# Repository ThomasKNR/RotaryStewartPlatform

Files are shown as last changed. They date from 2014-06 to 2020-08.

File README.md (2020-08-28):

Rotary Stewart Platform
-----------------------

In this repository are source files for a Rotary Stewart Platform project. This project is for a small Stewart platform controlled by RC servos and Arduino. Stewart Platform is a parallel robot capable of positioning its moving platform in 6 degrees of freedom. In this project, platform has additional features such as an LCD to show various data and IrDA used for remote controlling of its movements. Main informations about this project and detailed description of a construction process can be found at http://www.instructables.com/id/Arduino-controlled-Rotary-Stewart-Platform/.

Source files are divided into three main folders:

- **src_arduino_code** - contains souce code files and needed libraries for Arduino:
 - for controlling LCD via I2C interface: https://bitbucket.org/fmalpartida/new-liquidcrystal/wiki/Home
 -  for IrDA communication: https://github.com/shirriff/Arduino-IRremote/wiki
- **src_comm_lib** - contains communication library for controlling this platform, it is written in C++ and uses serial communication to communicate with arduino. This library works on Windows and on Linux, it is used for easy control of platform movements.
- **templates_for_cutting** - DXF files containing templates for laser cutting of parts from plastic and also PCB layout for board needed for external supply of power to servos. These files were made using QCad tool.

In IrDA communication library there are made tiny changes - because servo and also IrDA library need interrupt handling, there were problems when using servos and IrDA communication at the same time, these changes reduce consequence of these problems, consequences were very subtle random servo movements.

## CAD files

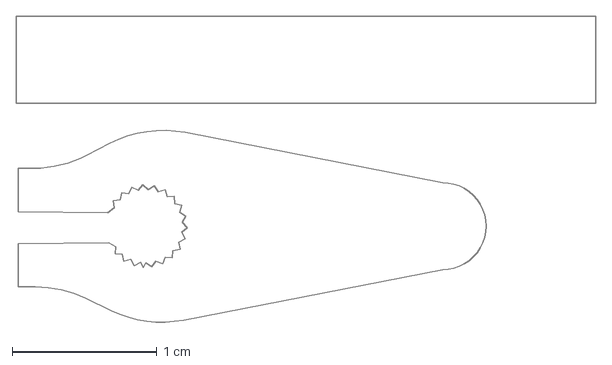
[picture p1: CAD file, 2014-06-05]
templates_for_cutting/servo_arm.dxf
4.00 x 2.13 cm

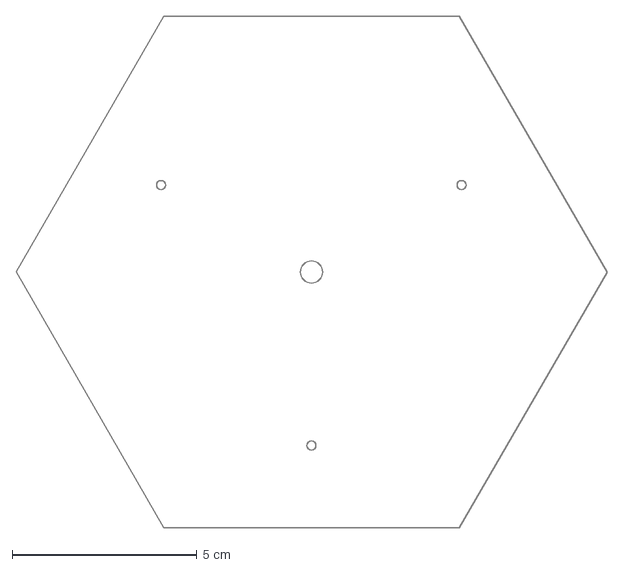
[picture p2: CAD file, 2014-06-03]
templates_for_cutting/platform_top.dxf
16.0 x 13.9 cm

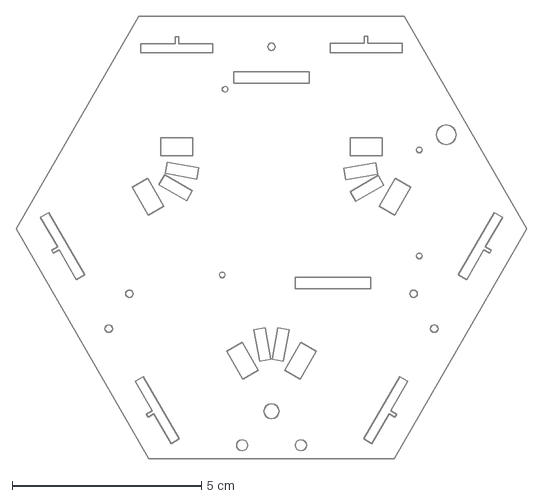
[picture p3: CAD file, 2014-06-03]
templates_for_cutting/base_top.dxf
13.5 x 11.7 cm

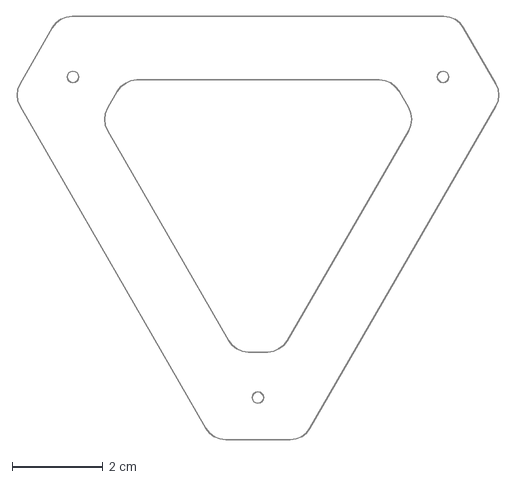
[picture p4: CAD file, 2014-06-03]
templates_for_cutting/platform_bot.dxf
10.6 x 9.31 cm

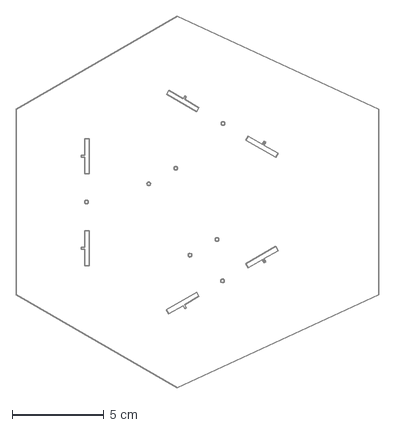
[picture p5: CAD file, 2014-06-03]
templates_for_cutting/base_bot.dxf
19.8 x 20.3 cm

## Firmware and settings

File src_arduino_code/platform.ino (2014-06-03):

/* <Controlling code for Arduino Controlled Rotary Stewart Platform>
    Copyright (C) <2014>  <Tomas Korgo>

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
    You should have received a copy of the GNU General Public License
    along with this program.  If not, see <http://www.gnu.org/licenses/>.*/

#include <Servo.h>
#include <Wire.h>
#include <LCD.h>
#include <LiquidCrystal_I2C.h>
#include <IRremote.h>

//define values of IrDA codes send from used remote control
#define MUTE_BUTTON 0x807F906F
#define STANDBY_ON 0x807F20DF
#define VOL_UP 0x807F609F
#define VOL_DOWN 0x807FA05F
#define DVD 0x807F08F7
#define TV 0x807F8877
#define GAME 0x807F48B7
#define CD 0x807FC837

//define of characters used for control of serial communication ['0'-'8']
#define SETBACKOFF 48
#define SETBACKON 49
#define SETPOSITIONS 50
#define PRINTPOS 51
#define STOPPRINTPOS 52
#define SWITCHIRDA 53
#define SETPOSITIONSINMS 54
#define SWITCHIRDAOFF 55
#define GEPOSITION 56
//defines of LCD pin numbers, most probably they dont have to be changed except of I2C_ADDR which value is neccessary and have to be changed.
#define I2C_ADDR 0x27
#define LCD 1
#define IrDA 1
#define BACKLIGHT_PIN 3
#define En 2
#define Rw 1
#define Rs 0
#define D4 4
#define D5 5
#define D6 6
#define D7 7
//MIN and MAX PWM pulse sizes, they can be found in servo documentation
#define MAX 2200
#define MIN 800

//Positions of servos mounted in opposite direction
#define INV1 1
#define INV2 3
#define INV3 5

//constants for computation of positions of connection points
#define pi  3.14159
#define deg2rad 180/pi
#define deg30 pi/6
//variables used for proper show of positions on LCD
char shown=0, showPos=0, useIrda=0;
unsigned long time;

//variable to store connected LCD
LiquidCrystal_I2C lcd(I2C_ADDR, En, Rw, Rs, D4,D5,D6,D7);
//IrReciever variables
IRrecv irrecv(12); // Receive Ir on digital pin n 12
decode_results results;

//Array of servo objects
Servo servo[6];
//Zero positions of servos, in this positions their arms are perfectly horizontal, in us
static int zero[6]={1475,1470,1490,1480,1460,1490};
//In this array is stored requested position for platform - x,y,z,rot(x),rot(y),rot(z)
static float arr[6]={0,0.0,0, radians(0),radians(0),radians(0)};
//Actual degree of rotation of all servo arms, they start at 0 - horizontal, used to reduce
//complexity of calculating new degree of rotation
static float theta_a[6]={0.0,0.0,0.0, 0.0,0.0,0.0};
//Array of current servo positions in us
static int servo_pos[6];
//rotation of servo arms in respect to axis x
const float beta[] = {pi/2,-pi/2,-pi/6, 5*pi/6,-5*pi/6,pi/6},
//maximum servo positions, 0 is horizontal position
      servo_min=radians(-80),servo_max=radians(80),
//servo_mult - multiplier used for conversion radians->servo pulse in us
//L1-effective length of servo arm, L2 - length of base and platform connecting arm
//z_home - height of platform above base, 0 is height of servo arms
servo_mult=400/(pi/4),L1 = 0.79,L2 = 4.66, z_home = 4.05;
//RD distance from center of platform to attachment points (arm attachment point)
//RD distance from center of base to center of servo rotation points (servo axis)
//theta_p-angle between two servo axis points, theta_r - between platform attachment points
//theta_angle-helper variable
//p[][]=x y values for servo rotation points
//re[]{}=x y z values of platform attachment points positions
//equations used for p and re will affect postion of X axis, they can be changed to achieve
//specific X axis position
const float RD = 2.42,PD =2.99,theta_p = radians(37.5),
theta_angle=(pi/3-theta_p)/2, theta_r = radians(8),
      p[2][6]={
          {
            -PD*cos(deg30-theta_angle),-PD*cos(deg30-theta_angle),
            PD*sin(theta_angle),PD*cos(deg30+theta_angle),
            PD*cos(deg30+theta_angle),PD*sin(theta_angle)
         },
         {
            -PD*sin(deg30-theta_angle),PD*sin(deg30-theta_angle),
            PD*cos(theta_angle),PD*sin(deg30+theta_angle),
            -PD*sin(deg30+theta_angle),-PD*cos(theta_angle)
         }
      },
      re[3][6] = {
          {
              -RD*sin(deg30+theta_r/2),-RD*sin(deg30+theta_r/2),
              -RD*sin(deg30-theta_r/2),RD*cos(theta_r/2),
              RD*cos(theta_r/2),-RD*sin(deg30-theta_r/2),
          },{
              -RD*cos(deg30+theta_r/2),RD*cos(deg30+theta_r/2),
              RD*cos(deg30-theta_r/2),RD*sin(theta_r/2),
              -RD*sin(theta_r/2),-RD*cos(deg30-theta_r/2),
          },{
              0,0,0,0,0,0
          }
};
//arrays used for servo rotation calculation
//H[]-center position of platform can be moved with respect to base, this is
//translation vector representing this move
static float M[3][3], rxp[3][6], T[3], H[3] = {0,0,z_home};

void setup(){
//LCD inicialisation and turning on the backlight
#if LCD
   lcd.begin(16,2);
   lcd.setBacklightPin(BACKLIGHT_PIN, POSITIVE);
   lcd.setBacklight(HIGH);
   lcd.home();
#endif

//attachment of servos to PWM digital pins of arduino
   servo[0].attach(3, MIN, MAX);
   servo[1].attach(5, MIN, MAX);
   servo[2].attach(6, MIN, MAX);
   servo[3].attach(9, MIN, MAX);
   servo[4].attach(10, MIN, MAX);
   servo[5].attach(11, MIN, MAX);
//begin of serial communication
   Serial.begin(9600);
//putting into base position
   setPos(arr);
}

//function calculating needed servo rotation value
float getAlpha(int *i){
   static int n;
   static float th=0;
   static float q[3], dl[3], dl2;
   double min=servo_min;
   double max=servo_max;
   n=0;
   th=theta_a[*i];
   while(n<20){
    //calculation of position of base attachment point (point on servo arm where is leg connected)
      q[0] = L1*cos(th)*cos(beta[*i]) + p[0][*i];
      q[1] = L1*cos(th)*sin(beta[*i]) + p[1][*i];
      q[2] = L1*sin(th);
    //calculation of distance between according platform attachment point and base attachment point
      dl[0] = rxp[0][*i] - q[0];
      dl[1] = rxp[1][*i] - q[1];
      dl[2] = rxp[2][*i] - q[2];
      dl2 = sqrt(dl[0]*dl[0] + dl[1]*dl[1] + dl[2]*dl[2]);
    //if this distance is the same as leg length, value of theta_a is corrent, we return it
      if(abs(L2-dl2)<0.01){
         return th;
      }
    //if not, we split the searched space in half, then try next value
      if(dl2<L2){
         max=th;
      }else{
         min=th;
      }
      n+=1;
      if(max==servo_min || min==servo_max){
         return th;
      }
      th = min+(max-min)/2;
   }
   return th;
}

//function calculating rotation matrix
void getmatrix(float pe[])
{
   float psi=pe[5];
   float theta=pe[4];
   float phi=pe[3];
   M[0][0] = cos(psi)*cos(theta);
   M[1][0] = -sin(psi)*cos(phi)+cos(psi)*sin(theta)*sin(phi);
   M[2][0] = sin(psi)*sin(phi)+cos(psi)*cos(phi)*sin(theta);

   M[0][1] = sin(psi)*cos(theta);
   M[1][1] = cos(psi)*cos(phi)+sin(psi)*sin(theta)*sin(phi);
   M[2][1] = cos(theta)*sin(phi);

   M[0][2] = -sin(theta);
   M[1][2] = -cos(psi)*sin(phi)+sin(psi)*sin(theta)*cos(phi);
   M[2][2] = cos(theta)*cos(phi);
}
//calculates wanted position of platform attachment poins using calculated rotation matrix
//and translation vector
void getrxp(float pe[])
{
   for(int i=0;i<6;i++){
      rxp[0][i] = T[0]+M[0][0]*(re[0][i])+M[0][1]*(re[1][i])+M[0][2]*(re[2][i]);
      rxp[1][i] = T[1]+M[1][0]*(re[0][i])+M[1][1]*(re[1][i])+M[1][2]*(re[2][i]);
      rxp[2][i] = T[2]+M[2][0]*(re[0][i])+M[2][1]*(re[1][i])+M[2][2]*(re[2][i]);
   }
}
//function calculating translation vector - desired move vector + home translation vector
void getT(float pe[])
{
   T[0] = pe[0]+H[0];
   T[1] = pe[1]+H[1];
   T[2] = pe[2]+H[2];
}

unsigned char setPos(float pe[]){
    unsigned char errorcount;
    errorcount=0;
    for(int i = 0; i < 6; i++)
    {
        getT(pe);
        getmatrix(pe);
        getrxp(pe);
        theta_a[i]=getAlpha(&i);
        if(i==INV1||i==INV2||i==INV3){
            servo_pos[i] = constrain(zero[i] - (theta_a[i])*servo_mult, MIN,MAX);
        }
        else{
            servo_pos[i] = constrain(zero[i] + (theta_a[i])*servo_mult, MIN,MAX);
        }
    }

    for(int i = 0; i < 6; i++)
    {
        if(theta_a[i]==servo_min||theta_a[i]==servo_max||servo_pos[i]==MIN||servo_pos[i]==MAX){
            errorcount++;
        }
        servo[i].writeMicroseconds(servo_pos[i]);
    }
    return errorcount;
}

//functions used for displaying actual platform position on 16x2 LCD display
#if LCD
void showRot(){
   lcd.setCursor(0,0);
   lcd.print("Rot");
   lcd.setCursor(12,0);
   lcd.print((int)(arr[3]*deg2rad));
   lcd.setCursor(3,1);
   lcd.print((int)(arr[4]*deg2rad));
   lcd.setCursor(11,1);
   lcd.print((int)(arr[5]*deg2rad));
}
void showComm(){
   if(shown==0){
      shown=1;
      lcd.setCursor(3,0);
      lcd.print("ation x: ");
      lcd.setCursor(0,1);
      lcd.print("y: ");
      lcd.setCursor(8,1);
      lcd.print("z: ");
   }
}
void clearNr(){
   lcd.setCursor(12,0);
   lcd.print("    ");
   lcd.setCursor(3,1);
   lcd.print("     ");
   lcd.setCursor(11,1);
   lcd.print("     ");

}
void showLoc(){
   lcd.setCursor(0,0);
   lcd.print("Loc");
   lcd.setCursor(12,0);
   lcd.print((int)(arr[0]*25.4));
   lcd.setCursor(3,1);
   lcd.print((int)(arr[1]*25.4));
   lcd.setCursor(11,1);
   lcd.print((int)(arr[2]*25.4));
}
#endif

//main control loop, obtain requested action from serial connection, then execute it
void loop()
{

   if(Serial.available()>0){
      int input=Serial.read();
      switch(input){
//action to turn backlight off
         case SETBACKOFF:
#if LCD
            lcd.setBacklight(LOW);
#endif
            break;
//action to turn backlight on
         case SETBACKON:
#if LCD
            lcd.setBacklight(HIGH);
#endif
            break;
//action to change position of platform, obtain 6 values representing desired position
         case SETPOSITIONS:
            for(int i=0;i<6;i++){
               long kk;
               while(Serial.available()<4){
                  ;
               }
               kk=(long)Serial.read();
               kk=kk+(Serial.read()<<8);
               kk=kk+(Serial.read()<<16);
               kk=kk+(Serial.read()<<24);
               if(i<3){
                  arr[i]=(kk/100)/25.4;
               }else{
                  arr[i]=radians(kk/100.0);
               }
            }
            Serial.write(setPos(arr));
            Serial.flush();
            break;
//enable of showing current position on LCD
         case PRINTPOS:
#if LCD
            showPos=PRINTPOS;
            time=millis();
#endif
            break;
//enable of controlling platformy by IrDA remote
        case SWITCHIRDA:
#if IrDA
            irrecv.enableIRIn();
            useIrda=SWITCHIRDA;
#endif
            break;
//reserved for future use - possiblity to send just servo timing values
//main control would be executed on communicating partner
         case SETPOSITIONSINMS:
            for(int i=0;i<6;i++){
               long kk;
               while(Serial.available()<4){
                  ;
               }
               kk=(long)Serial.read();
               kk=kk|(Serial.read()<<8);
               kk=kk|(Serial.read()<<16);
               kk=kk|(Serial.read()<<24);
               servo[i].writeMicroseconds(kk);
            }
            break;
//disable of showing current position on LCD
         case STOPPRINTPOS:
            showPos=STOPPRINTPOS;
            shown=0;
            break;
//disable of controlling platformy by IrDA remote
         case SWITCHIRDAOFF:
            useIrda=SWITCHIRDAOFF;
            break;
//return current position of platform
         case GEPOSITION:
            retPos();
            break;
         default:
            break;
      }
   }
//helping subroutine to print current position
#if LCD
   if(showPos==PRINTPOS){
      static byte act=0;
      showComm();
      if(millis()-time<1500){
         act=0;
      }else if(millis()-time<3000){
         if(act==0){
            act=1;
            clearNr();
            showRot();
         }
      }else{
         time=millis();
         clearNr();
         showLoc();
      }
   }
#endif
//this part is used for IrDA position control
#if IrDA
   if(useIrda==SWITCHIRDA&&irrecv.decode(&results)){
      static byte val=0;
      switch(results.value){
         case MUTE_BUTTON:
            val=1;
            break;
         case STANDBY_ON:
            val=0;
            break;
         case VOL_UP:
            if(val<=2){
               arr[val]+=1;
            }else{
               arr[val]=radians((arr[val]*deg2rad)+0.4);
            }
            break;
         case VOL_DOWN:
            if(val<=2){
               arr[val]-=1;
            }else{
               arr[val]=radians((arr[val]*deg2rad)-0.4);
            }
            break;
         case DVD:
            val=2;
            break;
         case TV:
            val=3;
            break;
         case GAME:
            val=4;
            break;
         case CD:
            val=5;
            break;
      }
      setPos(arr);
      irrecv.resume(); // Continue receiving
   }
#endif

}

void retPos(){
   for(int i=0;i<6;i++){
       long val;
       if(i<3){
           val=(long)(arr[i]*100*25.4);
       }else{
           val=(long)(arr[i]*100*deg2rad);
       }
       Serial.write(val);
       Serial.write((val>>8));
       Serial.write((val>>16));
       Serial.write((val>>24));
       Serial.flush();
   }
}

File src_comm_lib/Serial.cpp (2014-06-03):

/* <Soure file for library used for communication with
 * Arduino Controlled Rotary Stewart Platform>
 * Copyright (C) <2014>  <Tomas Korgo>
 *
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
 * You should have received a copy of the GNU General Public License
 * along with this program.  If not, see <http://www.gnu.org/licenses/>.*/
#include "SerialClass.h"

//action numbers
#define SETBACKOFF 48
#define SETBACKON 49
#define SETPOSITIONS 50
#define PRINTPOS 51
#define STOPPRINTPOS 52
#define SWITCHIRDA 53
#define SETPOSITIONSINMS 54
#define SWITCHIRDAOFF 55
#define GEPOSITION 56


Platform::Platform(int portno){
#ifdef _WIN32
	if (!serial.Open(portno, 9600)){
        error=2;
        fprintf(stderr,"COM communication establish error\n");
    }
    //sleep for 2.5s in case Arduino restarts
	Sleep(2500);
#elif defined __linux__
    this->arduino = fopen("/dev/ttyACM0","r+b");
    if(this->arduino==NULL){
        this->arduino = fopen("/dev/ttyACM1","r+b");
        if(this->arduino==NULL){
            this->error=2;
            fprintf(stderr,"Path to Arduino is bad\n");
        }
    }
    sleep(3);
#endif
}

bool Platform::writeAction(unsigned char c){
#ifdef _WIN32
    if(serial.IsOpened()){
        if(!serial.SendData(&c,1)){
            error=1;
            return false;
        }
		return true;
    }else{
        error=2;
        return false;
    }
#elif defined __linux__
    if(this->arduino==NULL){
        this->error=2;
        return false;
    }else{
        if(fwrite(&c,sizeof(char), 1, this->arduino)<1){
            this->error=1;
            return false;
        }
        fflush(this->arduino);
        return true;
    }
#endif
}

bool Platform::setBacklightOff(){
    char val=SETBACKOFF;
    return(this->writeAction(val));
}
bool Platform::setBacklightOn(){
    char val=SETBACKON;
    return(this->writeAction(val));
}

bool Platform::printPositions(){
    char val=PRINTPOS;
    return(this->writeAction(val));
}

bool Platform::irDaOn(){
    char val=SWITCHIRDAOFF;
    return(this->writeAction(val));
}
bool Platform::irDaOff(){
    char val=SWITCHIRDA;
    return(this->writeAction(val));
}
bool Platform::endPrintPositions(){
    char val=STOPPRINTPOS;
    return(this->writeAction(val));
}
bool Platform::setPositionsInMs(int *values){
    char val=SWITCHIRDA;
    if(!this->writeAction(val)){
        return false;
    }
#ifdef _WIN32
    if(serial.IsOpened()){
        for(int i=0;i<6;i++){
            int32_t vall=(int32_t)(100*values[i]);
            unsigned char arr[4]={(vall),(vall>>8),(vall>>16),(vall>>24) };
            if(!this->serial.SendData(arr,4)){
				error=1;
                return false;
            }
        }
		return true;
    }else{
        error=2;
        return false;
    }
#elif defined __linux__
    for(int i=0;i<6;i++){
        int32_t vall=(int32_t)(values[i]);
        if(fwrite(&vall,sizeof(int32_t), 1, this->arduino)<sizeof(int32_t)){
            this->error=1;
            return false;
        }
        fflush(this->arduino);
    }
    return true;
#endif
}
int Platform::setPositions(float * values){
    char val=SETPOSITIONS;
    if(!this->writeAction(val)){
        return false;
    }
#ifdef _WIN32
	if (this->serial.IsOpened()){
		for (int i = 0; i < 6; i++){
			int32_t vall = (int32_t)(100 * values[i]);
			unsigned char arr[4] = { (vall & 255), (vall >> 8) & 255, (vall >> 16) & 255, (vall >> 24) & 255 };
			if (!this->serial.SendData(arr, 4)){
				error = 1;
				return -1;
			}
		}
		char vall;
		byte arr[1];
		if ((vall = this->serial.ReadData(arr, 1)) < 1){
			error = 1;
			return -1;
		}
		return (int)arr[0];
    }else{
        error=2;
        return -1;
    }
#elif defined __linux__
    for(int i=0;i<6;i++){
        int32_t val=(int32_t)(100*values[i]);
        int lol;
        if((lol=fwrite(&val,sizeof(int32_t), 1, this->arduino))<1) {
            this->error=1;
            return -1;
        }
    }
    fflush(this->arduino);
    char vall;
    struct timespec tim, tim2;
    tim.tv_sec = 0;
    tim.tv_nsec = 230000000;
    nanosleep(&tim , &tim2);
    if(fread(&vall,1,1,this->arduino)<1){
        this->error=1;
        return -1;
    }
    return (int)vall;
#endif
}
bool Platform::getPositions(float * values){
        char val=GEPOSITION;
    if(!this->writeAction(val)){
        return false;
    }
#ifdef _WIN32
    if(this->serial.IsOpened()){
        for(int i=0;i<6;i++){
            int32_t vall;
            byte arr[4];
            if((vall=this->serial.ReadData(arr,4))<4){
                error=1;
                return false;
            }
			vall = arr[3];
            vall=(vall<<8)|arr[2];
            vall=(vall<<8)|arr[1];
            vall=(vall<<8)|arr[0];
			values[i]=(float)(vall/100.00);
        }
		return true;
    }else{
        error=2;
        return false;
    }
#elif defined __linux__
            struct timespec tim, tim2;
            tim.tv_sec = 0;
            tim.tv_nsec = 150000000;
            nanosleep(&tim , &tim2);
        for(int i=0;i<6;i++){
            int32_t vall;
            if(fread(&vall,sizeof(int32_t),1,this->arduino)<1){
                this->error=1;
                return false;
            }
            values[i]=vall/100.00;

            fflush(this->arduino);
        }
        return true;
#endif
}


void Platform::endCommunication(){
#ifdef _WIN32
    this->serial.Close();
#elif defined __linux__
    if(this->arduino==NULL){
        this->error=1;
    }else{
        fflush(this->arduino);
        fclose(this->arduino);
    }
#endif
}
#ifdef _WIN32
CSerial::CSerial()
{

	memset(&m_OverlappedRead, 0, sizeof(OVERLAPPED));
	memset(&m_OverlappedWrite, 0, sizeof(OVERLAPPED));
	m_hIDComDev = NULL;
	m_bOpened = FALSE;

}

CSerial::~CSerial()
{

	Close();

}
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

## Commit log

2014-06-03 init commit
    [base_bot.dxf, base_top.dxf, platform_bot.dxf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]
2014-06-05 Change in formatting of readme, adding of servo arm template file
    [servo_arm.dxf]

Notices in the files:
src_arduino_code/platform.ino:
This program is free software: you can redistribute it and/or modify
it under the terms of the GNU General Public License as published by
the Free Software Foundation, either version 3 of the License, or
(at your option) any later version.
